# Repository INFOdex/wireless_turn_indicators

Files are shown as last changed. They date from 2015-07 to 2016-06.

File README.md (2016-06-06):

# Testing of Wireless Turn Indicators for Automotive Applications
Created as a capstone project for Robert S. and Peter L.

This project was mostly done as a proof-of-concept, but was eventually completed as a capstone project. 

The final copy of the code was stored on the university's private GIT server.

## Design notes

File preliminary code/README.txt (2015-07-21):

Author: Peter Lenardis

This folder contains a file containing code used to prove that an LED could blink upon the push of a button. The file is the only one besides the README in this folder.

This tested the LED quality and the button quality as a byproduct.

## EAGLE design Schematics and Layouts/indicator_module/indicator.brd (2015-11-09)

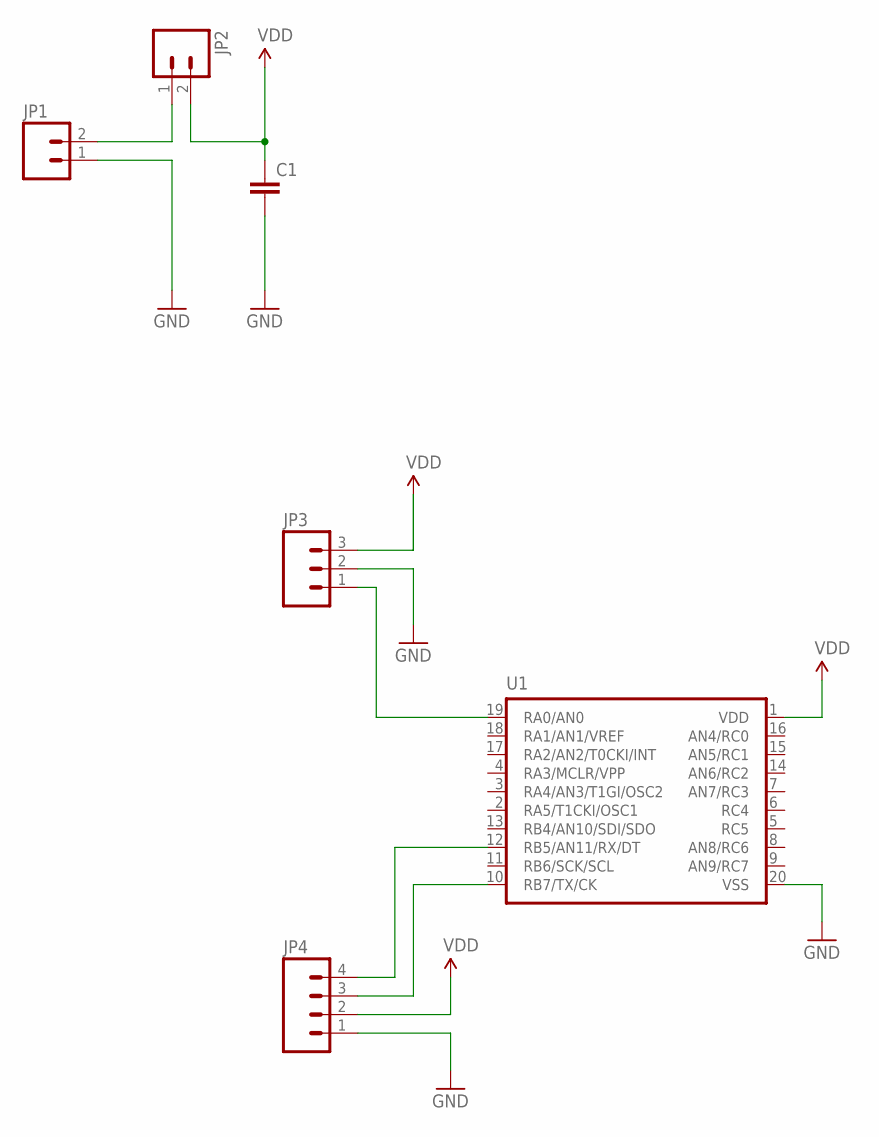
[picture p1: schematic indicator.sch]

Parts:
C1: CAPPTH1; CAP-PTH-5MM
JP1, JP2: M02PTH; 1X02
JP3: M03PTH; 1X03
JP4: M04PTH; 1X04
U1: PIC16F6XX; DIL20

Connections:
GND: C1.2, JP1.1, JP3.2, JP4.1, U1.20 (VSS)
unnamed: JP1.2, JP2.1
unnamed: JP3.1, U1.19 (RA0/AN0)
unnamed: JP4.4, U1.12 (RB5/AN11/RX/DT)
unnamed: JP4.3, U1.10 (RB7/TX/CK)
VDD: C1.1, JP2.2, JP3.3, JP4.2, U1.1 (VDD)

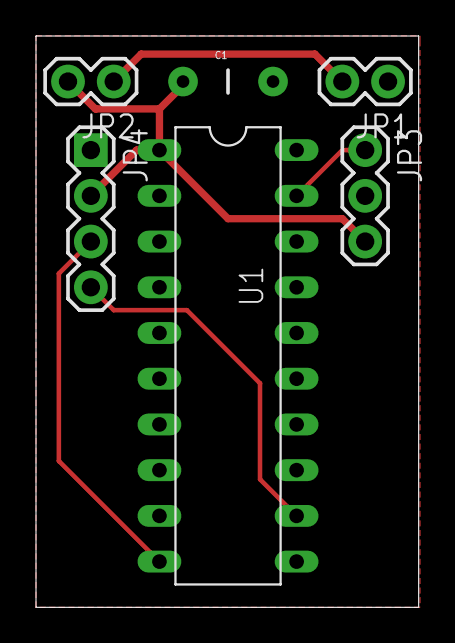
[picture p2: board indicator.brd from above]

Board: 2 copper layers, 21.3 x 31.7 mm, 6 parts (0 on the bottom side), 6 nets.

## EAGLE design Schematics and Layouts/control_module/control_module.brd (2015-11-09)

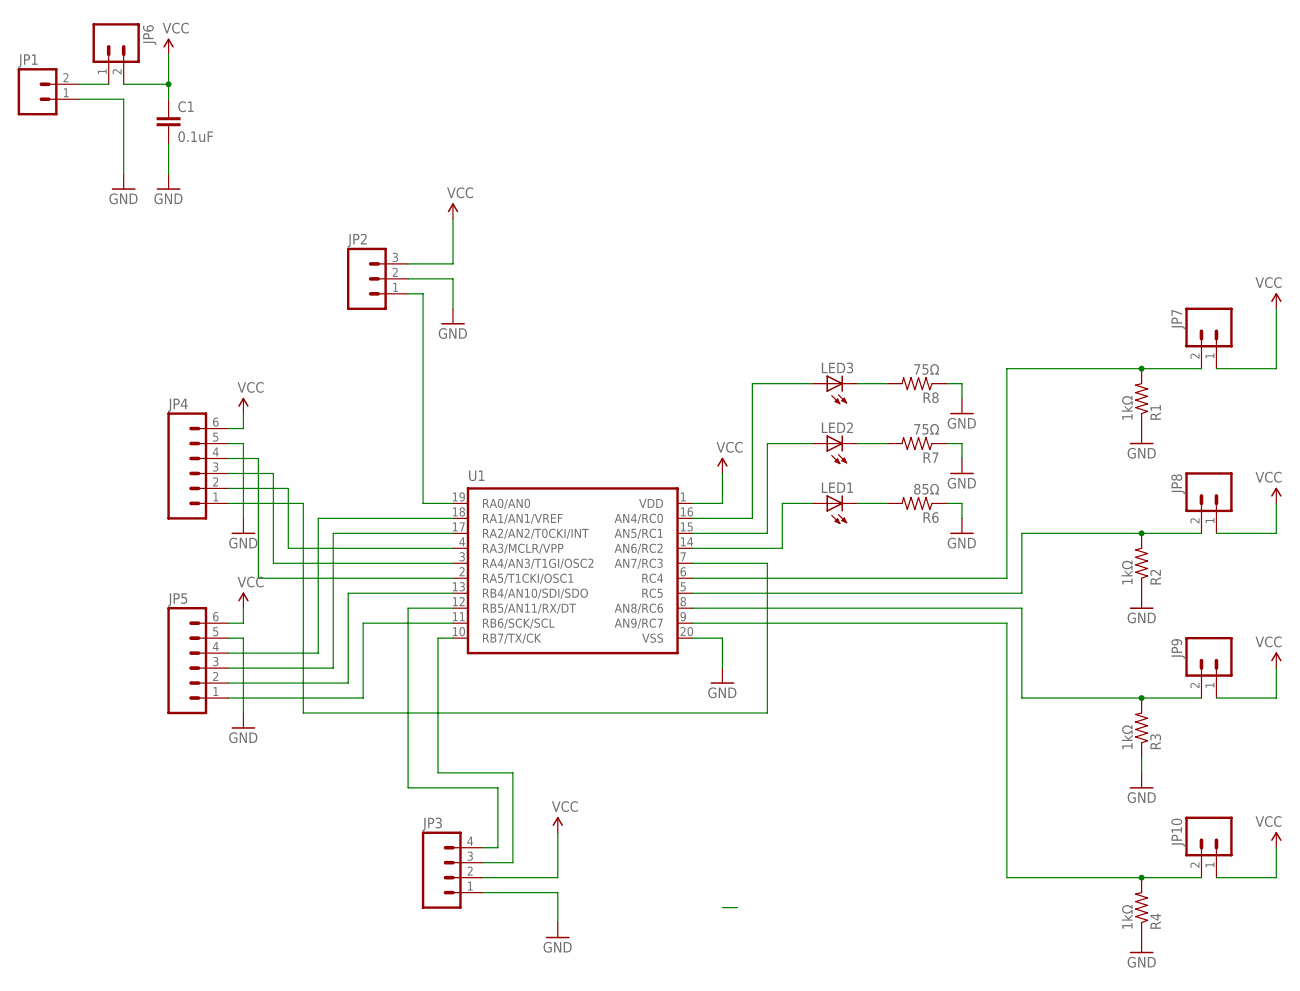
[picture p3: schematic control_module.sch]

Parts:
C1: 0.1uF; CAP-PTH-5MM
JP1, JP6, JP7, JP8, JP9, JP10: M02PTH; 1X02
JP2: M03PTH; 1X03
JP3: M04PTH; 1X04
JP4, JP5: M06SILK_FEMALE_PTH; 1X06
LED1, LED2, LED3: LED3MM
R1, R2, R3, R4: 1kΩ; AXIAL-0.4
R6: 85Ω; AXIAL-0.4
R7, R8: 75Ω; AXIAL-0.4
U1: PIC16F6XX; DIL20

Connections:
GND: C1.2, JP1.1, JP2.2, JP3.1, JP4.5, JP5.5, R1.P$1 (1), R2.P$1 (1), R3.P$1 (1), R4.P$1 (1), R6.P$1 (1), R7.P$1 (1), R8.P$1 (1), U1.20 (VSS)
unnamed: JP8.2, R2.P$2 (2), U1.5 (RC5)
unnamed: JP9.2, R3.P$2 (2), U1.8 (AN8/RC6)
unnamed: JP3.4, U1.12 (RB5/AN11/RX/DT)
unnamed: JP10.2, R4.P$2 (2), U1.9 (AN9/RC7)
unnamed: JP2.1, U1.19 (RA0/AN0)
unnamed: LED3.A, U1.16 (AN4/RC0)
unnamed: LED1.K (C), R6.P$2 (2)
unnamed: LED2.A, U1.15 (AN5/RC1)
unnamed: LED2.K (C), R7.P$2 (2)
unnamed: LED1.A, U1.14 (AN6/RC2)
unnamed: LED3.K (C), R8.P$2 (2)
unnamed: JP3.3, U1.10 (RB7/TX/CK)
unnamed: JP4.1, U1.7 (AN7/RC3)
unnamed: JP4.2, U1.4 (RA3/MCLR/VPP)
unnamed: JP4.3, U1.3 (RA4/AN3/T1GI/OSC2)
unnamed: JP4.4, U1.2 (RA5/T1CKI/OSC1)
unnamed: JP5.4, U1.18 (RA1/AN1/VREF)
unnamed: JP5.3, U1.17 (RA2/AN2/T0CKI/INT)
unnamed: JP5.2, U1.13 (RB4/AN10/SDI/SDO)
unnamed: JP1.2, JP6.1
unnamed: JP7.2, R1.P$2 (2), U1.6 (RC4)
unnamed: JP5.1, U1.11 (RB6/SCK/SCL)
VCC: C1.1, JP2.3, JP3.2, JP4.6, JP5.6, JP6.2, JP7.1, JP8.1, JP9.1, JP10.1, U1.1 (VDD)

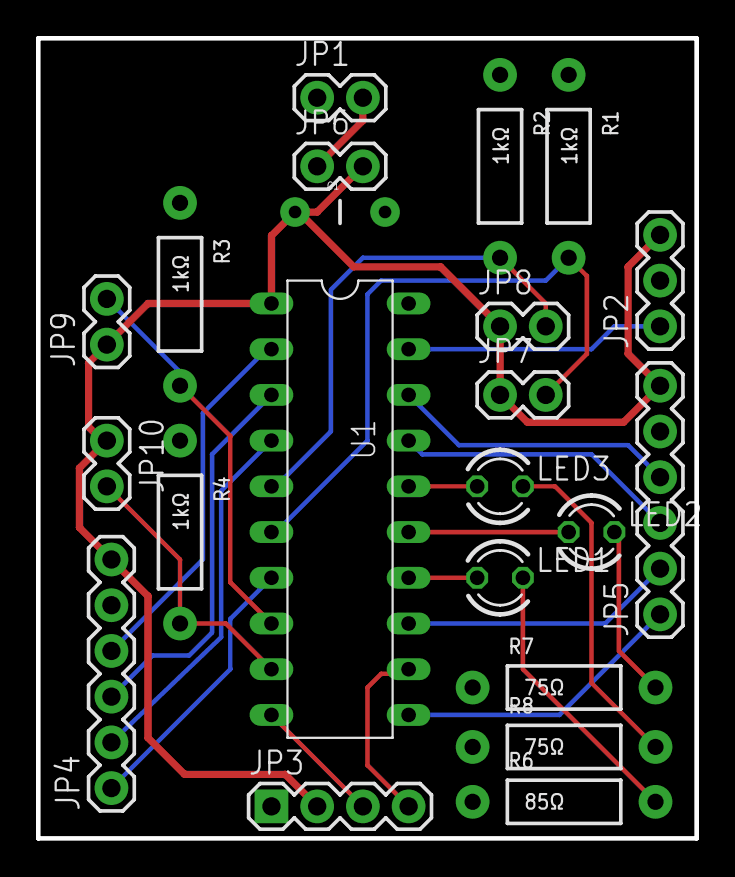
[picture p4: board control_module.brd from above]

Board: 2 copper layers, 36.6 x 44.5 mm, 22 parts (0 on the bottom side), 24 nets.

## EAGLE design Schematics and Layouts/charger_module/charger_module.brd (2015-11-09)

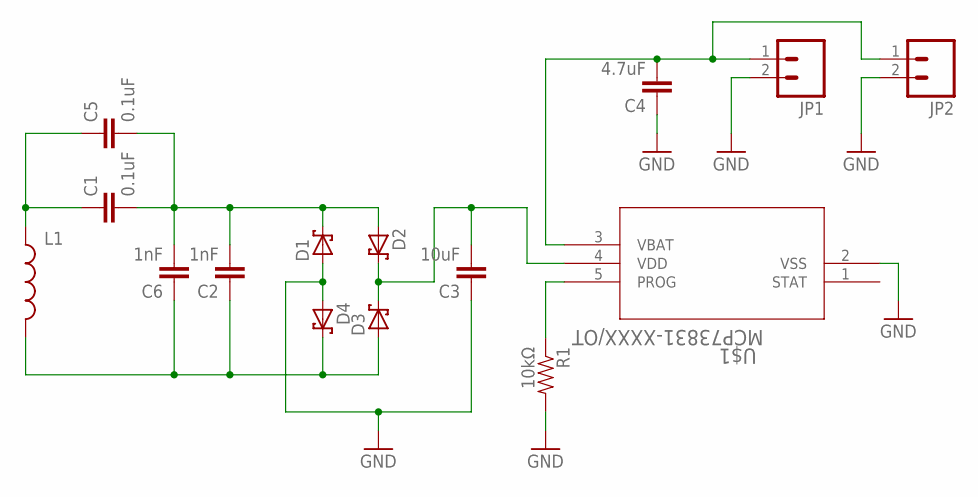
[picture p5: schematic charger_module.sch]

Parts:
C1, C5: 0.1uF; CAP-PTH-5MM
C2, C6: 1nF; CAP-PTH-5MM
C3: 10uF; CAP-PTH-5MM
C4: 4.7uF; CAP-PTH-5MM
D1, D2, D3, D4: SCHOTTKY-DIODECB417-15; CB417-15
JP1, JP2: M02PTH; 1X02
L1: INDUCTORAXIAL-0.6; AXIAL-0.6
R1: 10kΩ; AXIAL-0.3
U$1: MCP73831-XXXX/OT; SOT-23-5_MC

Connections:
GND: C3.1, C4.1, D1.A, D4.A, JP1.2, JP2.2, R1.P$2 (2), U$1.2 (VSS)
unnamed: C1.1, C5.1, L1.P$1 (1)
unnamed: C1.2, C2.2, C5.2, C6.2, D1.C, D2.A
unnamed: C3.2, D2.C, D3.C, U$1.4 (VDD)
unnamed: C4.2, JP1.1, JP2.1, U$1.3 (VBAT)
unnamed: C2.1, C6.1, D3.A, D4.C, L1.P$2 (2)
unnamed: R1.P$1 (1), U$1.5 (PROG)

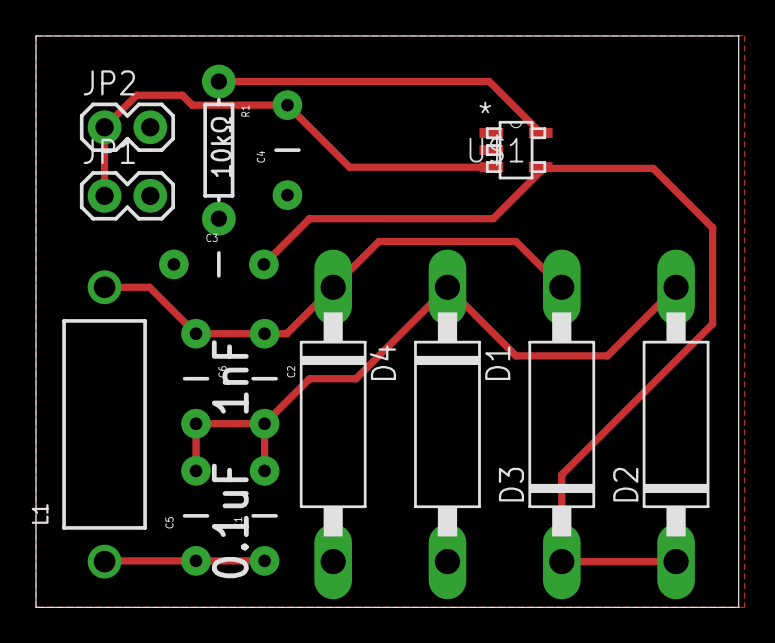
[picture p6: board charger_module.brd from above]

Board: 2 copper layers, 39.0 x 31.7 mm, 15 parts (0 on the bottom side), 7 nets.

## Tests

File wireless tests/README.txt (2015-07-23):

Author: Peter Lenardis

In the two folders are the proof-of-concept for the transmitter and receiver.

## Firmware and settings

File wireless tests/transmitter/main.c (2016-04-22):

#include "uart.h"
#include <pic.h>
#include <htc.h>
#define _LEGACY_HEADERS

// CONFIG
#pragma config FOSC = INTRCIO   // Oscillator Selection bits (INTOSCIO oscillator: I/O function on RA4/OSC2/CLKOUT pin, I/O function on RA5/OSC1/CLKIN)
#pragma config WDTE = OFF       // Watchdog Timer Enable bit (WDT disabled and can be enabled by SWDTEN bit of the WDTCON register)
#pragma config PWRTE = OFF      // Power-up Timer Enable bit (PWRT disabled)
#pragma config MCLRE = OFF      // MCLR Pin Function Select bit (MCLR pin function is digital input, MCLR internally tied to VDD)
#pragma config CP = OFF         // Code Protection bit (Program memory code protection is disabled)
#pragma config CPD = OFF        // Data Code Protection bit (Data memory code protection is disabled)
#pragma config BOREN = OFF      // Brown-out Reset Selection bits (BOR disabled)
#pragma config IESO = OFF       // Internal External Switchover bit (Internal External Switchover mode is disabled)
#pragma config FCMEN = OFF      // Fail-Safe Clock Monitor Enabled bit (Fail-Safe Clock Monitor is disabled)


volatile char count = 0;	//counter to keep track of time in interrupt
volatile int state = 0;     //binary, digital state machine for reset
volatile char buff = 0;		//buffer to be sent
volatile char workaround;   //used to send X (all cancel) via interrupt
volatile char r_blink = 0;	//boolean to denote state of right indicator
volatile char l_blink = 0;	//boolean to denote state of left indicator
volatile char h_blink = 0;	//boolean to denote state of hazard mode
volatile char error_chk = 0; //buffer with error checking result

/*------LEGEND------*/
//X is for all cancel

//R is for right blink
//L is for left blink
//H is for hazard mode
/*------------------*/


void init(void);	//initialization function prototype

void interrupt ISR(void){	//interrupt routine for dash indicator blinking
    //for(int i = 0; i<10000; i++);
    if(RA5 && RABIF){
        count = PORTA;              //read from portA to clear interrupt
        RABIF = 0;                  //clear the flag
        if(l_blink || r_blink || h_blink){
            workaround = 1;                 //for use outside interrupt
        }
        l_blink = 0;        //left off
        r_blink = 0;        //right off
        h_blink = 0;        //hazard mode off
        PORTC = 0;
    }
}

int main(void) {
	RABIF = 0;         //turn off button interrupt flag for good measure
    init();			
	for(int i = 0; i<25000; i++);	//delay used to make sure that UART is set up
	RABIF = 0;          //turn it off again, because it is finicky

	while (1) {
		while((PORTC && 0xF0) == 0);	//check PORTC for button push, hang here if not pushed
		/*TURN LEFT*/	
            while(!l_blink && RC5) {		//RC5 (Left) is pushed & not blinking
				while(RC5);			//debounce
				buff = 76;			//L
				RC1 = 1;            //turn light on to show visual feedback
				UART_sendch(buff);  //send signal to XBee
				l_blink = 1;		//change state to BLINK
            /*----error checking begins below----*/
                for(int i = 0;!RCIF;i++){       //getting response from indicator
                    for(int i = 0; i<10; i++);  //this delay was calibrated via trial and error
                    if(i>10000){                //don't wait here forever (timeout)
                        RC2 = 1;                //ERROR!
                        break;
                    }
                }
                while(RCIF){
                    error_chk = RCREG;          //read the register message until empty
                }
                if(error_chk != 83){ //make sure not garbage
                    RC2 =1;                 //else: ERROR!
                    error_chk = 0;  //reset error-checking buffer after ERROR
                }
                error_chk = 0;      //reset error-checking buffer after success
            /*---error checking completed----*/
                while(l_blink){
                    RC1 = !RC1;     //toggle LED state
                    for(int i = 0; i<27000; i++);   //delay
                }
				
			}
		/*TURN RIGHT*/
			while(!r_blink && RC4) {		//RC4 (Right) is pushed & not blinking
				while(RC4);			//debounce
				buff = 82;			//R
				RC0 = 1;            //turn on LED for visual feedback
				UART_sendch(buff);  //send data to XBee
				r_blink = 1;		//change state to BLINK
                
                for(int i = 0;!RCIF;i++){       //getting response from indicator
                    for(int i = 0; i<10; i++);  //this delay was calibrated via trial and error
                    if(i>10000){                //don't wait here forever (timeout)
                        RC2 = 1;                //ERROR!
                        break;          
                    }
                }
                while(RCIF){
                    error_chk = RCREG;          //read the register message until empty
                }
                if(error_chk != 83){ //make sure not garbage
                    RC2 =1;                 //else: ERROR!
                    error_chk = 0;  //reset error-checking variable after ERROR!
                }
                error_chk = 0;      //reset error-checking variable after success
                
                while(r_blink){
                    RC0 = !RC0;     //toggle LED state
                    for(int i = 0; i<27000; i++);   //delay
                }
			}
		/*HAZARD MODE*/	
			while(!h_blink && RC7) {			//RC7 (Hazard) is pushed
				while(RC7);			//debounce
				buff = 72;			//H
				UART_sendch(buff);  //send data to XBee
				RC0 = 1;			//turn on both dash indicators
				RC1 = 0;            //asynchronously...
				h_blink = 1;		//change state to blink for both indicators
				r_blink = 1;
				l_blink = 1;
                while(h_blink){
                    RC0 = !RC0; //toggle both
                    RC1 = !RC1; //LED states
                    for(int i = 0; i<27000; i++);
                }
			}
        
        if(workaround){     //send all cancel if interrupt sets "workaround" to 1
            buff = 88;          //X
            UART_sendch(buff);  //send data to XBee
            workaround = 0;     //reset workaround        
        }
	}
	return 0;

}


void init(void) {

	//set internal oscillator to 4 MHz (default)
	OSCCON|=0b00111000;

	//set pin RA0 to output
	TRISA=0x3F;

	//set pin RB0 to output
	TRISB=0x00;

	//set pin RC0 to output
	TRISC=0xF0;

	//Initialize PORTS A,B and C
	PORTA=0;
	PORTB=0;
	PORTC=0;

	//configure the device to run as a digital input 
	ANSEL=0;
	ANSELH=0;
	
	//disable comparators
	//CM1CON0 = 0;        //Initialize comp 1 off 
    //CM2CON0 = 0;        //Initialize comp 2 off 

	//Configure Interrupt On Change for RA5
	INTCON = 0x00; 
    IOCA5 = 1;          //Enabled RA5 Interrupt-On-Change 
    RABIF = 0;          //Enabled Interrupt-On-Change Interupt
    RABIE = 1;
    RABIF = 0;
	//INTCON = 0b00001000;
	GIE = 1;		//enable Global interrupts
	
	//ADC_init();
	UART_init();

	
//	RB4=0;
//	RB6=0;
//	delayms(50);
//	RB4=1;
//	RB6=1;
//	delayms(50);
	//RB4=0;
	//RB6=0;
}

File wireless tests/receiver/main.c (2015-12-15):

#include "timer.h"
#include "uart.h"
#include <pic.h>

__CONFIG (FOSC_XT & WDTE_OFF & PWRTE_ON, BOREN_OFF & LVP_OFF & CPD_OFF & WRT_OFF);

char buff = 0;			//buffer to be recieved
char lastbuff = 0;		//the previous buffer (error checking)
char blink = 0;			//binary state machine to determine command mode status
char TooManyS = 0;		//binary state machine to determine error in data recieved
char i;					//counter

void init(void);

int main(void) 
{	
	init();
	delayms(1000);		//used to insure the initializations

	while (1) {

		while(!RCIF) {
			while(!RCIF);		//wait for the recieved data flag
		}
		if(RCIF){
			lastbuff = FERR;	//check for framing errors
			lastbuff = buff;	//keep track of the last buffer
			buff = RCREG;		//get the new buffer from register
		} 

		if ((buff == 82) || (buff == 72)) {
			blink = 1;		//if buff is R or H, command mode on
			
			if (lastbuff == buff) {
				TooManyS = 1;		//check if R is put in twice
			}
			
			RC2 = 1;			//turn on light
			buff = 83;			//change buffer
			UART_sendch(buff);	//send confirmation "s"
			RC2 = 0;			//turn off light		
		}

		if (buff != 82) {
			TooManyS = 0;		//R is not in there twice
		}

		if ((buff == 88)) {
			blink = 0;				//if buff is X, turn off command mode
			RC2 = 0;
		}

		if ((blink == 1) && (!TooManyS)) {
			while(!RCIF){ 
				RC2 = !RC2;			//send the value in buff, if all is good
				delayms(700);
				}
		}	
		//i++;
	}
	return 0;

}


void init(void) {

	//set internal oscillator to 500 kHz
	//and run from external clock defined by FOSC
	//if no FOSC, 4MHz internal clock is default
	OSCCON|=0b00111000;

	//set pin RA0 to output
	TRISA=0;

	//set pin RB0 to output
	TRISB=0;

	//set pin RC0 to output
	TRISC=0;

	//Initialize PORTS A,B and C
	PORTA=0;
	PORTB=0;
	PORTC=0;

	//configure the device to run as a digital input 
	ANSEL=0;
	ANSELH=0;
	

	UART_init();

	
//	RB4=0;
//	RB6=0;
//	delayms(50);
//	RB4=1;
//	RB6=1;
//	delayms(50);
	//RB4=0;
	//RB6=0;
}

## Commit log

2015-07-21 Blinks LED
    (readme included for more detail)
2015-07-22 Start of wireless module testing
    Work in progress... transmitter/receiver still unable to communicate.
    Poor documentation for modules chosen. System works with Xbees, but not
    cheaper modules.
2015-07-23 Transmitter and Receiver Proof of concept updates
    added extra LED for confirmation of button press, and got receiver to
    work properly.
2015-09-30 Transmitter Modification
    Closer to demo version of the code. This is able to blink two different
    lights wirelessly and (mostly) seamlessly.
2015-11-09 Qualifiers (revision 1)
    Schematics, PCB layouts, and a demo version of the code have been
    created/committed.
    [charger_breakout.brd, charger_breakout.sch, charger_module.brd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]
2015-11-17 Qualifiers Week (final edit)
    Everything works as intended. An indication of error on the transmitter
    module is implemented and is triggered by error on the indicator module.
    [main.c]
2015-12-15 Design Review (final FINAL edit)
    Changed when the error is reported (before blinking feedback) and
    changed the error handling to be more robust.
    [main.c]
2015-12-15 Added files
    Libraries that I authored to communicate with the XBee via UART.

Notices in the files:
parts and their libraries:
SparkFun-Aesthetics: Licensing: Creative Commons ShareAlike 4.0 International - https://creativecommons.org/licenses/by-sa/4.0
